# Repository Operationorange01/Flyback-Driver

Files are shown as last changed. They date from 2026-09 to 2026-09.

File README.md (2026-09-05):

This is a driver for a High Voltage Flyback Transformer. 
we are planning on using it in the next stage in our research on EHD propulsion. You can read our preprint from last year here: https://doi.org/10.31224/6625

Features:
 - Variable duty cycle
 - Variable frequency
 - Current/Voltage Sensing
 - Current/Voltage Regulating 6V to 25V, digitally adjustable via 12-bit DAC about 5mV resolution
 - Rotary encoder for control
 - OLED Display
 - Indicator Lights
 - Soft Startup
 - Hardware overcurrent protection, independent of firmware
 - Latching fault shutdown
 - Adjustable trip threshold
 - RCD clamp with tunable clamp voltage

No firmware yet but coming soon

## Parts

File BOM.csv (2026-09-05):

Country of Origin may be different at time of shipment.
The HTSUS and ECCN information shown is for informational purposes only and is not a representation or warranty as to the accuracy or reliability of these classifications. All information is provided "as is" and is subject to change without notice. Any use made of the information provided is without recourse to Digi-Key and at the user's risk.
Index | Manufacturer Part Number | Manufacturer Name | Description | Lead Time | Availability | Stock Status | Attrition % | Requested Quantity 1 | Pack Quantity 1 | Pack Type 1 | Digi-Key Part Number 1 | Unit Price 1 | Extended Price 1 | Minimum Order Quantity 1 | Customer Reference | Requested Part Number | Lead Weeks | Datasheet | Reference Designator | US Import Tariff | Note | Part Status | RoHS Status | REACH Status | Moisture Sensitivity Level (MSL) | ECCN | HTSUS | Country of Origin | Environmental Information | Original Part numbers | Unit of Measure | Image | Product Notes
1 | 78439369150 | Würth Elektronik | FIXED IND 15UH 8.3A 14.8 MOHM |  | 1,296 | In Stock |  | 1 | 1 | Cut Tape (CT) | 732-78439369150CT-ND | 5.27000 | $5.27 | 1 |  | 732-78439369150TR-ND | 43 | https://www.we-online.com/components/products/datasheet/78439369150.pdf |  | May apply on shipments to the U.S. |  | Active | ROHS3 Compliant | REACH Unaffected | 1 (Unlimited) | EAR99 | 8504.50.8000 | China | https://mm.digikey.com/Volume0/opasdata/d220001/medias/docus/744/Certificate_of_Compliance_ROHS.pdf | 732-78439369150TR-ND | Each | https://mm.digikey.com/Volume0/opasdata/d220001/medias/images/4170/MFG_WE-XHMA_7843xxxxxxx.jpg
2 | LCXND4040TKL2R2MDG | Taiyo Yuden | FIXED IND 2.2UH 2.2A 42 MOHM SMD |  | 2,876 | In Stock |  | 1 | 1 | Cut Tape (CT) | 587-LCXND4040TKL2R2MDGCT-ND | 0.30000 | $0.30 | 1 |  | 587-LCXND4040TKL2R2MDGTR-ND | 16 | https://mm.digikey.com/Volume0/opasdata/d220001/medias/docus/5883/LCXND4040TKL2R2MDG_SS.pdf |  | May apply on shipments to the U.S. |  | Active | ROHS3 Compliant | REACH Unaffected | 1 (Unlimited) | EAR99 | 8504.50.8000 | Philippines |  | 587-LCXND4040TKL2R2MDGTR-ND | Each | https://mm.digikey.com/Volume0/opasdata/d220001/medias/images/3541/MFG_LCXND4040TKL2R2MDG.jpg
3 | DR127-151-R | Eaton - Electronics Division | FIXED IND 150UH 1.59A 247 MOHM |  | 21,450 | In Stock |  | 1 | 1 | Cut Tape (CT) | 283-DR127-151-RCT-ND | 0.88000 | $0.88 | 1 |  | 283-DR127-151-RTR-ND | 24 | https://www.eaton.com/content/dam/eaton/products/electronic-components/resources/data-sheet/eaton-dr-high-power-density-high-efficiency-shielded-drum-core-pow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 |  | May apply on shipments to the U.S. |  | Active | ROHS3 Compliant | REACH Unaffected | 1 (Unlimited) | EAR99 | 8504.50.4000 | China |  | 283-DR127-151-RTR-ND | Each | https://mm.digikey.com/Volume0/opasdata/d220001/medias/images/567/DR127-151-R.JPG
4 | EC11E15244B2 | Alps Alpine | ENCODER MECH QUAD VERT PC PIN |  | 1,052 | In Stock |  | 1 | 1 | Tray | 4809-EC11E15244B2-ND | 5.00000 | $5.00 | 1 |  | 4809-EC11E15244B2-ND | 20 | https://mm.digikey.com/Volume0/opasdata/d220001/medias/docus/6727/alps_alps-s-a0008379064-1-1733314-1-13.pdf |  | May apply on shipments to the U.S. |  | Active | ROHS3 Compliant |  | 1 (Unlimited) | EAR99 | 8543.70.4500 | China |  | 4809-EC11E15244B2-ND | Each | https://mm.digikey.com/Volume0/opasdata/d220001/medias/images/5373/MFG_EC11E15244B2.jpg
5 | STM32F103C8T6 | STMicroelectronics | IC MCU 32BIT 64KB FLASH 48LQFP |  | 8,319 | In Stock |  | 1 | 1 | Tray | 497-6063-ND | 8.24000 | $8.24 | 1 |  | 497-6063-ND | 40 | https://www.st.com/resource/en/datasheet/stm32f103cb.pdf |  | May apply on shipments to the U.S. |  | Active | ROHS3 Compliant | REACH Unaffected | 3 (168 Hours) | 3A991A2 | 8542.31.0025 | Taiwan |  | 497-6063-ND | Each | https://mm.digikey.com/Volume0/opasdata/d220001/medias/images/389/48-LQFP.jpg
6 | UCC27511ADBVR | Texas Instruments | IC GATE DRVR LOW-SIDE SOT23-6 |  | 2,033 | In Stock |  | 1 | 1 | Cut Tape (CT) | 296-49474-1-ND | 1.14000 | $1.14 | 1 |  | 296-49474-2-ND | 16 | https://www.ti.com/general/docs/suppproductinfo.tsp?distId=10 |  | May apply on shipments to the U.S. |  | Active | ROHS3 Compliant | REACH Unaffected | 2 (1 Year) | EAR99 | 8542.39.0070 | China |  | 296-49474-2-ND | Each | https://mm.digikey.com/Volume0/opasdata/d220001/derivates/6/003/245/337/MFG_296%7E4073253-5%7EDBV%7E6_web%28640x640%29.jpg
7 | MCP4725A0T-E/CH | Microchip Technology | IC DAC 12BIT SOT-23-6 |  | 16,209 | In Stock |  | 2 | 2 | Cut Tape (CT) | MCP4725A0T-E/CHCT-ND | 1.27000 | $2.54 | 1 |  | MCP4725A0T-E/CHCT-ND | 13 | https://ww1.microchip.com/downloads/aemDocuments/documents/MSLD/ProductDocuments/DataSheets/MCP4725-Data-Sheet-20002039E.pdf |  | May apply on shipments to the U.S. |  | Active | ROHS3 Compliant | REACH Unaffected | 1 (Unlimited) | EAR99 | 8542.39.0040 | Thailand | https://ww1.microchip.com/downloads/aemDocuments/documents/corporate-responsibilty/environmental/product-regulatory-information/Semiconductor_EnvCoC.pdf|https://ww1.microchip.com/downloads/aemDocuments/documents/corporate-responsibilty/environmental/product-regulatory-information/Microchip_REACH_Statement.pdf | MCP4725A0T-E/CHCT-ND | Each | https://mm.digikey.com/Volume0/opasdata/d220001/derivates/6/003/238/121/MFG_150%7EC04-028%7ECH%2COT%7E6_web%28640x640%29.jpg
8 | INA226AIDGSR | Texas Instruments | IC CURRENT MONITOR 0.02% 10VSSOP |  | 94,948 | In Stock |  | 1 | 1 | Cut Tape (CT) | 296-29034-1-ND | 2.82000 | $2.82 | 1 |  | 296-29034-1-ND | 16 | https://www.ti.com/general/docs/suppproductinfo.tsp?distId=10 |  | May apply on shipments to the U.S. |  | Active | ROHS3 Compliant | REACH Unaffected | 2 (1 Year) | EAR99 | 8542.39.0070 | China |  | 296-29034-1-ND | Each | https://mm.digikey.com/Volume0/opasdata/d220001/medias/images/4190/296%7E4073272%7EDGS%7E10.JPG
9 | LM5117PSQ/NOPB | Texas Instruments | IC REG CTRLR BUCK 24WQFN |  | 4,037 | In Stock |  | 1 | 1 | Cut Tape (CT) | 296-LM5117PSQ/NOPBCT-ND | 7.46000 | $7.46 | 1 |  | 296-LM5117PSQ/NOPBCT-ND | 9 | https://www.ti.com/general/docs/suppproductinfo.tsp?distId=10 |  | - |  | Active | ROHS3 Compliant | REACH Unaffected | 1 (Unlimited) | EAR99 | 8542.39.0070 | Malaysia |  | 296-LM5117PSQ/NOPBCT-ND | Each | https://mm.digikey.com/Volume0/opasdata/d220001/medias/images/698/296%7E4206244%7ERTW%7E24.JPG
10 | LM2596S-ADJ | UMW | IC REG BUCK ADJ 3A TO263-5L |  | 98 | In Stock |  | 1 | 1 | Cut Tape (CT) | 4518-LM2596S-ADJCT-ND | 3.42000 | $3.42 | 1 |  | 4518-LM2596S-ADJCT-ND | 8 | https://www.umw-ic.com/static/pdf/08a395a0d66ae7472f74e2947a1d8a0f.pdf |  | - |  | Active | ROHS3 Compliant | REACH Unaffected | 1 (Unlimited) | EAR99 | 8542.39.0060 | China | https://mm.digikey.com/Volume0/opasdata/d220001/medias/docus/5791/UTD%20REACH%20SGS%20223%20Jan%202022%20Package.pdf|https://mm.digikey.com/Volume0/opasdata/d220001/medias/docus/5791/UTD%20RoHS3%20SGS%20Package.pdf | 4518-LM2596S-ADJCT-ND | Each | https://mm.digikey.com/Volume0/opasdata/d220001/medias/images/3602/MFG_LM2596S-ADJ%281%29.jpg
11 | TPS62130RGTT | Texas Instruments | IC REG BUCK ADJ 3A 16VQFN |  | 2,406 | In Stock |  | 1 | 1 | Cut Tape (CT) | 296-29934-1-ND | 3.07000 | $3.07 | 1 |  | 296-29934-2-ND | 16 | https://www.ti.com/general/docs/suppproductinfo.tsp?distId=10 |  | May apply on shipments to the U.S. |  | Active | ROHS3 Compliant | REACH Unaffected | 2 (1 Year) | EAR99 | 8542.39.0070 | China |  | 296-37682-1-ND | Each | https://mm.digikey.com/Volume0/opasdata/d220001/medias/images/4117/296%7E4222419%7ERGT%7E16.JPG
12 | LM393DR | Texas Instruments | IC COMPARATOR 2CH 8-SOIC |  | 131,872 | In Stock |  | 1 | 1 | Cut Tape (CT) | 296-1015-1-ND | 0.24000 | $0.24 | 1 |  | 296-1015-1-ND | 16 | https://www.ti.com/lit/ds/symlink/lm193.pdf?ts=1640569642482 |  | May apply on shipments to the U.S. |  | Active | ROHS3 Compliant | REACH Unaffected | 1 (Unlimited) | EAR99 | 8542.39.0090 | Mexico |  | 296-1015-1-ND | Each | https://mm.digikey.com/Volume0/opasdata/d220001/derivates/6/003/251/211/MFG_296%7E4040047-3%7ED%7E8_web%28640x640%29.jpg
13 | 74HC132D | Toshiba Semiconductor and Storage | IC NAND 4-CIR 2-IN 14-SOIC |  | 3,528 | In Stock - Non-Stock |  | 1 | 1 | Cut Tape (CT) | 264-74HC132DCT-ND | 0.43000 | $0.43 | 1 |  | 264-74HC132DCT-ND | 52 |  |  | - |  | Obsolete | ROHS3 Compliant | REACH Unaffected | 1 (Unlimited) | EAR99 | 8542.39.0070 | Japan |  | 264-74HC132DCT-ND | Each | https://mm.digikey.com/Volume0/opasdata/d220001/medias/images/2245/264%3B14SOIC-3.9%3B%3B14.jpg | Non Cancellable Non Returnable.
14 | IRFP460PBF | Vishay Siliconix | MOSFET N-CH 500V 20A TO247-3 |  | 18,673 | In Stock |  | 2 | 2 | Tube | IRFP460PBF-ND | 9.39000 | $18.78 | 1 |  | IRFP460PBF-ND | 27 | https://www.vishay.com/docs/91237/91237.pdf |  | May apply on shipments to the U.S. |  | Active | ROHS3 Compliant | REACH Unaffected | 1 (Unlimited) | EAR99 | 8541.29.0055 | United Kingdom |  | IRFP460PBF-ND | Each | https://mm.digikey.com/Volume0/opasdata/d220001/derivates/6/003/212/994/742%7E5971%7EP%7E3_web%28640x640%29.jpg
15 | IRF4905PBF | Infineon Technologies | MOSFET P-CH 55V 74A TO220AB |  | 39,590 | In Stock |  | 1 | 1 | Tube | IRF4905PBF-ND | 3.26000 | $3.26 | 1 |  | IRF4905PBF-ND | 16 | https://www.infineon.com/dgdl/irf4905pbf.pdf?fileId=5546d462533600a4015355e329b1197e |  | May apply on shipments to the U.S. |  | Active | ROHS3 Compliant | REACH Unaffected | 1 (Unlimited) | EAR99 | 8541.29.0055 | China |  | IRF4905PBF-ND | Each | https://mm.digikey.com/Volume0/opasdata/d220001/derivates/6/003/238/574/TO-220AB%2CTO-220-3%2CHEXFET%C2%AE_web%28640x640%29.jpg
16 | IRLZ44NPBF | Infineon Technologies | MOSFET N-CH 55V 47A TO220AB |  | 28,258 | In Stock |  | 2 | 2 | Tube | IRLZ44NPBF-ND | 1.80000 | $3.60 | 1 |  | IRLZ44NPBF-ND | 26 | https://www.infineon.com/dgdl/irlz44npbf.pdf?fileId=5546d462533600a40153567217c32725 |  | May apply on shipments to the U.S. |  | Active | ROHS3 Compliant | REACH Unaffected | 1 (Unlimited) | EAR99 | 8541.29.0055 | China |  | IRLZ44NPBF-ND | Each | https://mm.digikey.com/Volume0/opasdata/d220001/derivates/6/003/238/574/TO-220AB%2CTO-220-3%2CHEXFET%C2%AE_web%28640x640%29.jpg
17 | SMAJ12CA | Littelfuse Inc. | TVS DIODE 12VWM 19.9VC DO214AC |  | 28,364 | In Stock |  | 1 | 1 | Cut Tape (CT) | SMAJ12CALFCT-ND | 0.48000 | $0.48 | 1 |  | SMAJ12CALFCT-ND | 22 | https://www.littelfuse.com/assetdocs/tvs-diodes-smaj-datasheet?assetguid=13c2a823-03b8-4d1f-9ddc-9b44670aed9d |  | May apply on shipments to the U.S. |  | Active | ROHS3 Compliant | REACH Affected | 1 (Unlimited) | EAR99 | 8541.10.0080 | China | https://www.littelfusebusinesscenter.com/LFWeb/rohs_upload/RoHS_Certificate_of_Compliance/CoC_RoHS9_SMAJ12CA_05-08-2018.pdf | SMAJ12CALFCT-ND | Each | https://mm.digikey.com/Volume0/opasdata/d220001/derivates/6/001/123/964/118%7EDO214AC%28SMA%29%7E%7E2_web%28640x640%29.jpg
18 | SMCJ33A | Littelfuse Inc. | TVS DIODE 33VWM 53.3VC DO214AB |  | 60,353 | In Stock |  | 1 | 1 | Cut Tape (CT) | SMCJ33ALFCT-ND | 0.94000 | $0.94 | 1 |  | SMCJ33ALFCT-ND | 34 | https://www.littelfuse.com/assetdocs/littelfuse_tvs_diode_smcj_datasheet.pdf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 |  | May apply on shipments to the U.S. |  | Active | ROHS3 Compliant | REACH Affected | 1 (Unlimited) | EAR99 | 8541.10.0080 | China | https://www.littelfusebusinesscenter.com/LFWeb/rohs_upload/RoHS_Certificate_of_Compliance/CoC_RoHS9_SMCJ33A_06-13-2018.pdf | SMCJ33ALFCT-ND | Each | https://mm.digikey.com/Volume0/opasdata/d220001/derivates/6/003/248/763/MFG_18%7EDO214AB%28SMCJ%29%7E%7E2_web%28640x640%29.jpg
19 | 1N4148 | onsemi | DIODE STANDARD 100V 200MA DO35 |  | 727,505 | In Stock |  | 1 | 1 | Bulk | 1N4148FS-ND | 0.10000 | $0.10 | 1 |  | 1N4148FS-ND | 62 | https://www.onsemi.com/pub/Collateral/1N914-D.PDF |  | May apply on shipments to the U.S. |  | Active | ROHS3 Compliant | REACH Unaffected | Not Applicable | EAR99 | 8541.10.0070 | China | https://www.onsemi.com/site/pdf/RoHS-statement.pdf|https://www.onsemi.com/PowerSolutions/MaterialComposition.do?export=pdf&opnId=1N4148 | 1N4148FS-ND | Each | https://mm.digikey.com/Volume0/opasdata/d220001/medias/images/649/1N5229BFS.jpg
20 | SS36 | Taiwan Semiconductor Corporation | DIODE SCHOTTKY 60V 3A DO214AB |  | 8,916 | In Stock |  | 1 | 1 | Cut Tape (CT) | 1801-SS36CT-ND | 0.79000 | $0.79 | 1 |  | 1801-SS36CT-ND | 13 | https://services.taiwansemi.com/storage/resources/datasheet/SS32%20SERIES_Q2412.pdf |  | May apply on shipments to the U.S. |  | Active | ROHS3 Compliant | REACH Affected | 1 (Unlimited) | EAR99 | 8541.10.0080 | Taiwan | https://www.taiwansemi.com/en/wp-content/uploads/2023/12/Environment_Hazardous_Substances_Compliance_20231115.pdf|https://www.taiwansemi.com/en/wp-content/uploads/2023/12/REACH_regulation1907_2006_EC_compliance_240%20SVHCs_20240124_Web.pdf|https://services.taiwansemi.com/storage/resources/environmental_information/REACH%20regulation%20compliance_ANNEX%20XVII_20250708_Web.pdf|https://www.taiwansemi.com/en/wp-content/uploads/2023/12/California%20Proposition%2065%20Compliance_20240124_Web.pdf | 1801-SS36CT-ND | Each | https://mm.digikey.com/Volume0/opasdata/d220001/medias/images/6167/1801%7EDO214AB%28SMC%29%7E%7E2.jpg
21 | UF4007 | Taiwan Semiconductor Corporation | DIODE STANDARD 1000V 1A DO204AL |  | 1,259 | In Stock |  | 1 | 1 | Cut Tape (CT) | 1801-UF4007CT-ND | 0.42000 | $0.42 | 1 |  | 1801-UF4007CT-ND | 8 | https://services.taiwansemi.com/storage/resources/datasheet/UF4001%20SERIES_P2104.pdf |  | May apply on shipments to the U.S. |  | Active | ROHS3 Compliant | REACH Affected | 1 (Unlimited) | EAR99 | 8541.10.0080 | China | https://www.taiwansemi.com/en/wp-content/uploads/2023/12/Environment_Hazardous_Substances_Compliance_20231115.pdf|https://www.taiwansemi.com/en/wp-content/uploads/2023/12/REACH_regulation1907_2006_EC_compliance_240%20SVHCs_20240124_Web.pdf|https://services.taiwansemi.com/storage/resources/environmental_information/REACH%20regulation%20compliance_ANNEX%20XVII_20250708_Web.pdf|https://www.taiwansemi.com/en/wp-content/uploads/2023/12/California%20Proposition%2065%20Compliance_20240124_Web.pdf | 1801-UF4007CT-ND | Each | https://mm.digikey.com/Volume0/opasdata/d220001/medias/images/6285/1801%7EDO41%7E%7E2.jpg
22 | 1N4742A | onsemi | DIODE ZENER 12V 1W DO41 |  | 29,376 | In Stock |  | 1 | 1 | Bulk | 1N4742AFS-ND | 0.28000 | $0.28 | 1 |  | 1N4742AFS-ND | 50 | https://www.onsemi.com/pdf/datasheet/1n4736at-d.pdf |  | May apply on shipments to the U.S. |  | Active | ROHS3 Compliant | REACH Unaffected | Not Applicable | EAR99 | 8541.10.0050 | China | https://www.onsemi.com/site/pdf/RoHS-statement.pdf|https://www.onsemi.com/PowerSolutions/MaterialComposition.do?export=pdf&opnId=1N4742A | 1N4742AFS-ND | Each | https://mm.digikey.com/Volume0/opasdata/d220001/medias/images/6164/488%7EMKT-DO41A%7E%7E2.jpg
23 | CRF2512-FZ-R033ELF | Bourns Inc. | RES 0.033 OHM 1% 1W 2512 |  | 1,900 | In Stock |  | 1 | 1 | Cut Tape (CT) | CRF2512-FZ-R033ELFCT-ND | 0.49000 | $0.49 | 1 |  | CRF2512-FZ-R033ELFCT-ND | 23 | https://www.bourns.com/docs/Product-Datasheets/CRF.pdf |  | May apply on shipments to the U.S. |  | Active | ROHS3 Compliant | REACH Unaffected | 1 (Unlimited) | EAR99 | 8533.21.0030 | Taiwan | https://www.bourns.com/docs/Product-MDS/CRF2512_mds.pdf|https://mm.digikey.com/Volume0/opasdata/d220001/medias/docus/6657/Bourns%20REACH%20247%20Jan%202025%20Statement.pdf|https://www.bourns.com/docs/rohs-cofc/crx_coc2.pdf?sfvrsn=da0774f6_12 | CRF2512-FZ-R033ELFCT-ND | Each | https://mm.digikey.com/Volume0/opasdata/d220001/medias/images/4280/cmp2010.jpg
24 | WSL2512R0150FEA | Vishay Dale | RES 0.015 OHM 1% 1W 2512 |  | 12,011 | In Stock |  | 1 | 1 | Cut Tape (CT) | WSLG-.015CT-ND | 1.34000 | $1.34 | 1 |  | WSLG-.015CT-ND | 38 | https://www.vishay.com/docs/30100/wsl.pdf |  | May apply on shipments to the U.S. |  | Active | ROHS3 Compliant | REACH Unaffected | 1 (Unlimited) | EAR99 | 8533.21.0030 | Mexico |  | WSLG-.015CT-ND | Each | https://mm.digikey.com/Volume0/opasdata/d220001/derivates/6/002/690/354/WSL%202512_web%28640x640%29.jpg
25 | RSMF2JT100K | Stackpole Electronics Inc | RES 100K OHM 5% 2W AXIAL |  | 23,671 | In Stock |  | 1 | 1 | Cut Tape (CT) | RSMF2JT100KCT-ND | 0.19000 | $0.19 | 1 |  | RSMF2JT100KCT-ND | 19 | https://www.seielect.com/catalog/SEI-RSF_RSMF.pdf |  | May apply on shipments to the U.S. |  | Active | ROHS3 Compliant | REACH Unaffected | Not Applicable | EAR99 | 8533.21.0090 | China | https://www.seielect.com/catalog/SEI-RoHS_Compliance_Status.pdf|https://www.seielect.com/catalog/reach.pdf|https://www.seielect.com/catalog/sei-coc%20prop%2065.pdf | RSMF2JT100KCT-ND | Each | https://mm.digikey.com/Volume0/opasdata/d220001/medias/images/2498/100k-Ohm-RS%28M%29F-5%25-Axial-bl.jpg
26 | RK73H2ATTD1002F | KOA Speer Electronics, Inc. | RES 10K OHM 1% 1/4W 0805 |  | 1,155,716 | In Stock |  | 15 | 15 | Cut Tape (CT) | 2019-RK73H2ATTD1002FCT-ND | 0.03400 | $0.51 | 1 |  | 2019-RK73H2ATTD1002FCT-ND | 7 | https://www.koaspeer.com/pdfs/RK73H.pdf |  | May apply on shipments to the U.S. |  | Active | ROHS3 Compliant | REACH Unaffected | 1 (Unlimited) | EAR99 | 8533.21.0030 | Malaysia | https://www.koaglobal.com/product/common/rohs|https://mm.digikey.com/Volume0/opasdata/d220001/medias/docus/5718/2019_KOA%20Speer%20RoHS3%20Statement.pdf|https://mm.digikey.com/Volume0/opasdata/d220001/medias/docus/8955/KOA%20Speer%20CA%20Prop%2065%20Statement.pdf | 2019-RK73H2ATTD1002FCT-ND | Each | https://mm.digikey.com/Volume0/opasdata/d220001/medias/images/5572/MFG_RK73H1HTTCM12R7D.jpg
27 | RK73H2ATTD10R0F | KOA Speer Electronics, Inc. | RES 10 OHM 1% 1/4W 0805 |  | 210,232 | In Stock |  | 5 | 5 | Cut Tape (CT) | 2019-RK73H2ATTD10R0FCT-ND | 0.10000 | $0.50 | 1 |  | 2019-RK73H2ATTD10R0FCT-ND | 7 | https://www.koaspeer.com/pdfs/RK73H.pdf |  | May apply on shipments to the U.S. |  | Active | ROHS3 Compliant | REACH Unaffected | 1 (Unlimited) | EAR99 | 8533.21.0030 | Malaysia | https://www.koaglobal.com/product/common/rohs|https://mm.digikey.com/Volume0/opasdata/d220001/medias/docus/5718/2019_KOA%20Speer%20RoHS3%20Statement.pdf|https://mm.digikey.com/Volume0/opasdata/d220001/medias/docus/8955/KOA%20Speer%20CA%20Prop%2065%20Statement.pdf | 2019-RK73H2ATTD10R0FCT-ND | Each | https://mm.digikey.com/Volume0/opasdata/d220001/medias/images/5572/MFG_RK73H1HTTCM12R7D.jpg
28 | RK73H2ATTD3300F | KOA Speer Electronics, Inc. | RES 330 OHM 1% 1/4W 0805 |  | 80,638 | In Stock |  | 5 | 5 | Cut Tape (CT) | 2019-RK73H2ATTD3300FCT-ND | 0.10000 | $0.50 | 1 |  | 2019-RK73H2ATTD3300FCT-ND | 7 | https://www.koaspeer.com/pdfs/RK73H.pdf |  | May apply on shipments to the U.S. |  | Active | ROHS3 Compliant | REACH Unaffected | 1 (Unlimited) | EAR99 | 8533.21.0030 | Malaysia | https://www.koaglobal.com/product/common/rohs|https://mm.digikey.com/Volume0/opasdata/d220001/medias/docus/5718/2019_KOA%20Speer%20RoHS3%20Statement.pdf|https://mm.digikey.com/Volume0/opasdata/d220001/medias/docus/8955/KOA%20Speer%20CA%20Prop%2065%20Statement.pdf | 2019-RK73H2ATTD3300FCT-ND | Each | https://mm.digikey.com/Volume0/opasdata/d220001/medias/images/5572/MFG_RK73H1HTTCM12R7D.jpg
29 | RK73H2ATTD1003F | KOA Speer Electronics, Inc. | RES 100K OHM 1% 1/4W 0805 |  | 520,148 | In Stock |  | 5 | 5 | Cut Tape (CT) | 2019-RK73H2ATTD1003FCT-ND | 0.10000 | $0.50 | 1 |  | 2019-RK73H2ATTD1003FCT-ND | 7 | https://www.koaspeer.com/pdfs/RK73H.pdf |  | May apply on shipments to the U.S. |  | Active | ROHS3 Compliant | REACH Unaffected | 1 (Unlimited) | EAR99 | 8533.21.0030 | Malaysia | https://www.koaglobal.com/product/common/rohs|https://mm.digikey.com/Volume0/opasdata/d220001/medias/docus/5718/2019_KOA%20Speer%20RoHS3%20Statement.pdf|https://mm.digikey.com/Volume0/opasdata/d220001/medias/docus/8955/KOA%20Speer%20CA%20Prop%2065%20Statement.pdf | 2019-RK73H2ATTD1003FCT-ND | Each | https://mm.digikey.com/Volume0/opasdata/d220001/medias/images/5572/MFG_RK73H1HTTCM12R7D.jpg
30 | RK73H2ATTD1001F | KOA Speer Electronics, Inc. | RES 1K OHM 1% 1/4W 0805 |  | 422,806 | In Stock |  | 3 | 3 | Cut Tape (CT) | 2019-RK73H2ATTD1001FCT-ND | 0.10000 | $0.30 | 1 |  | 2019-RK73H2ATTD1001FCT-ND | 7 | https://www.koaspeer.com/pdfs/RK73H.pdf |  | May apply on shipments to the U.S. |  | Active | ROHS3 Compliant | REACH Unaffected | 1 (Unlimited) | EAR99 | 8533.21.0030 | Malaysia | https://www.koaglobal.com/product/common/rohs|https://mm.digikey.com/Volume0/opasdata/d220001/medias/docus/5718/2019_KOA%20Speer%20RoHS3%20Statement.pdf|https://mm.digikey.com/Volume0/opasdata/d220001/medias/docus/8955/KOA%20Speer%20CA%20Prop%2065%20Statement.pdf | 2019-RK73H2ATTD1001FCT-ND | Each | https://mm.digikey.com/Volume0/opasdata/d220001/medias/images/5572/MFG_RK73H1HTTCM12R7D.jpg
31 | RK73H2ATTDD4701F | KOA Speer Electronics, Inc. | RES 4.7K OHM 1% 1/4W 0805 |  | 25,015 | In Stock |  | 3 | 3 | Cut Tape (CT) | 2019-RK73H2ATTDD4701FCT-ND | 0.10000 | $0.30 | 1 |  | 2019-RK73H2ATTDD4701FCT-ND | 7 | https://www.koaspeer.com/pdfs/RK73H.pdf |  | May apply on shipments to the U.S. |  | Active | ROHS3 Compliant | REACH Unaffected | 1 (Unlimited) | EAR99 | 8533.21.0030 | Malaysia | https://www.koaglobal.com/product/common/rohs|https://mm.digikey.com/Volume0/opasdata/d220001/medias/docus/5718/2019_KOA%20Speer%20RoHS3%20Statement.pdf|https://mm.digikey.com/Volume0/opasdata/d220001/medias/docus/8955/KOA%20Speer%20CA%20Prop%2065%20Statement.pdf | 2019-RK73H2ATTDD4701FCT-ND | Each | https://mm.digikey.com/Volume0/opasdata/d220001/medias/images/5572/MFG_RK73H1HTTCM12R7D.jpg
32 | RK73H2ATTD2201F | KOA Speer Electronics, Inc. | RES 2.2K OHM 1% 1/4W 0805 |  | 116,635 | In Stock |  | 3 | 3 | Cut Tape (CT) | 2019-RK73H2ATTD2201FCT-ND | 0.10000 | $0.30 | 1 |  | 2019-RK73H2ATTD2201FCT-ND | 7 | https://www.koaspeer.com/pdfs/RK73H.pdf |  | May apply on shipments to the U.S. |  | Active | ROHS3 Compliant | REACH Unaffected | 1 (Unlimited) | EAR99 | 8533.21.0030 | Malaysia | https://www.koaglobal.com/product/common/rohs|https://mm.digikey.com/Volume0/opasdata/d220001/medias/docus/5718/2019_KOA%20Speer%20RoHS3%20Statement.pdf|https://mm.digikey.com/Volume0/opasdata/d220001/medias/docus/8955/KOA%20Speer%20CA%20Prop%2065%20Statement.pdf | 2019-RK73H2ATTD2201FCT-ND | Each | https://mm.digikey.com/Volume0/opasdata/d220001/medias/images/5572/MFG_RK73H1HTTCM12R7D.jpg
33 | RK73H2ATTD4R70F | KOA Speer Electronics, Inc. | RES 4.7 OHM 1% 1/4W 0805 |  | 72,302 | In Stock |  | 2 | 2 | Cut Tape (CT) | 2019-RK73H2ATTD4R70FCT-ND | 0.10000 | $0.20 | 1 |  | 2019-RK73H2ATTD4R70FCT-ND | 7 | https://www.koaspeer.com/pdfs/RK73H.pdf |  | May apply on shipments to the U.S. |  | Active | ROHS3 Compliant | REACH Unaffected | 1 (Unlimited) | EAR99 | 8533.21.0030 | Malaysia | https://www.koaglobal.com/product/common/rohs|https://mm.digikey.com/Volume0/opasdata/d220001/medias/docus/5718/2019_KOA%20Speer%20RoHS3%20Statement.pdf|https://mm.digikey.com/Volume0/opasdata/d220001/medias/docus/8955/KOA%20Speer%20CA%20Prop%2065%20Statement.pdf | 2019-RK73H2ATTD4R70FCT-ND | Each | https://mm.digikey.com/Volume0/opasdata/d220001/medias/images/5572/MFG_RK73H1HTTCM12R7D.jpg
34 | RC0805FR-07100RL | YAGEO | RES 100 OHM 1% 1/8W 0805 |  | 900,404 | In Stock |  | 4 | 4 | Cut Tape (CT) | 311-100CRCT-ND | 0.10000 | $0.40 | 1 |  | 311-100CRCT-ND | 17 | https://yageogroup.com/content/datasheet/asset/file/PYU-RC_GROUP_51_ROHS_L |  | May apply on shipments to the U.S. |  | Active | ROHS3 Compliant | REACH Unaffected | 1 (Unlimited) | EAR99 | 8533.21.0030 | Taiwan | https://www.yageogroup.com/content/Resource%20Library/Product%20Environmental%20Compliance/RoHS_Compliance_YAGEO.pdf | 311-100CRCT-ND | Each | https://mm.digikey.com/Volume0/opasdata/d220001/derivates/6/003/121/213/cut-tape-render_web%28640x640%29.jpg
35 | CRCW08054K12FKEA | Vishay Dale | RES SMD 4.12K OHM 1% 1/8W 0805 |  | 17,569 | In Stock |  | 2 | 2 | Cut Tape (CT) | 541-4.12KCCT-ND | 0.10000 | $0.20 | 1 |  | 541-4.12KCCT-ND | 21 | https://www.vishay.com/docs/20035/dcrcwe3.pdf |  | May apply on shipments to the U.S. |  | Active | ROHS3 Compliant | REACH Unaffected | 1 (Unlimited) | EAR99 | 8533.21.0030 | Israel |  | 541-4.12KCCT-ND | Each | https://mm.digikey.com/Volume0/opasdata/d220001/medias/images/4849/541_CRCW-0805-%282125metric%29.jpg
36 | RC0805FR-077K32L | YAGEO | RES 7.32K OHM 1% 1/8W 0805 |  | 28,715 | In Stock |  | 2 | 2 | Cut Tape (CT) | 311-7.32KCRCT-ND | 0.10000 | $0.20 | 1 |  | 311-7.32KCRCT-ND | 17 | https://yageogroup.com/content/datasheet/asset/file/PYU-RC_GROUP_51_ROHS_L |  | May apply on shipments to the U.S. |  | Active | ROHS3 Compliant | REACH Unaffected | 1 (Unlimited) | EAR99 | 8533.21.0030 | Taiwan | https://www.yageogroup.com/content/Resource%20Library/Product%20Environmental%20Compliance/RoHS_Compliance_YAGEO.pdf | 311-7.32KCRCT-ND | Each | https://mm.digikey.com/Volume0/opasdata/d220001/medias/images/4848/13_0805-%282012-metric%29.jpg
37 | CRG0805F13K | TE Connectivity Passive Product | RES SMD 13K OHM 1% 1/8W 0805 |  | 247,688 | In Stock |  | 2 | 2 | Cut Tape (CT) | A126339CT-ND | 0.10000 | $0.20 | 1 |  | A126339CT-ND | 14 | https://www.te.com/commerce/DocumentDelivery/DDEController?Action=srchrtrv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 |  | - |  | Active | ROHS3 Compliant | Vendor Undefined | 1 (Unlimited) | EAR99 | 8533.21.0030 | Thailand | https://www.te.com/commerce/alt/SinglePartSearch.do?PN=1623112-1&dest=stmt | A126339CT-ND | Each | https://mm.digikey.com/Volume0/opasdata/d220001/medias/images/2453/CRG%2C%20Neohm%200805%20%282012%20Metric%29.jpg
38 | RMCF0805FT17K4 | Stackpole Electronics Inc | RES 17.4K OHM 1% 1/8W 0805 |  | 274,182 | In Stock |  | 2 | 2 | Cut Tape (CT) | RMCF0805FT17K4CT-ND | 0.11000 | $0.22 | 1 |  | RMCF0805FT17K4CT-ND | 22 | https://www.seielect.com/catalog/SEI-RMCF_RMCP.pdf |  | May apply on shipments to the U.S. |  | Active | ROHS3 Compliant | REACH Unaffected | 1 (Unlimited) | EAR99 | 8533.21.0030 | China | https://www.seielect.com/catalog/SEI-RoHS_Compliance_Status.pdf|https://www.seielect.com/catalog/reach.pdf|https://www.seielect.com/catalog/sei-coc%20prop%2065.pdf | RMCF0805FT17K4CT-ND | Each | https://mm.digikey.com/Volume0/opasdata/d220001/derivates/6/002/683/989/MFG_RMC%20SERIES_web%28640x640%29.jpg
39 | RMCF0805FT33K0 | Stackpole Electronics Inc | RES 33K OHM 1% 1/8W 0805 |  | 172,439 | In Stock |  | 2 | 2 | Cut Tape (CT) | RMCF0805FT33K0CT-ND | 0.10000 | $0.20 | 1 |  | RMCF0805FT33K0CT-ND | 22 | https://www.seielect.com/catalog/SEI-RMCF_RMCP.pdf |  | May apply on shipments to the U.S. |  | Active | ROHS3 Compliant | REACH Unaffected | 1 (Unlimited) | EAR99 | 8533.21.0030 | Taiwan | https://www.seielect.com/catalog/SEI-RoHS_Compliance_Status.pdf|https://www.seielect.com/catalog/reach.pdf|https://www.seielect.com/catalog/sei-coc%20prop%2065.pdf | RMCF0805FT33K0CT-ND | Each | https://mm.digikey.com/Volume0/opasdata/d220001/medias/images/639/0805-RMCF-Series.jpg
40 | RC0805FR-07130KL | YAGEO | RES 130K OHM 1% 1/8W 0805 |  | 49,537 | In Stock |  | 2 | 2 | Cut Tape (CT) | 311-130KCRCT-ND | 0.10000 | $0.20 | 1 |  | 311-130KCRCT-ND | 17 | https://yageogroup.com/content/datasheet/asset/file/PYU-RC_GROUP_51_ROHS_L |  | May apply on shipments to the U.S. |  | Active | ROHS3 Compliant | REACH Unaffected | 1 (Unlimited) | EAR99 | 8533.21.0030 | Taiwan | https://www.yageogroup.com/content/Resource%20Library/Product%20Environmental%20Compliance/RoHS_Compliance_YAGEO.pdf | 311-130KCRCT-ND | Each | https://mm.digikey.com/Volume0/opasdata/d220001/medias/images/4848/13_0805-%282012-metric%29.jpg
41 | RK73H2ATTD3003F | KOA Speer Electronics, Inc. | RES 300K OHM 1% 1/4W 0805 |  | 17,760 | In Stock |  | 2 | 2 | Cut Tape (CT) | 2019-RK73H2ATTD3003FCT-ND | 0.10000 | $0.20 | 1 |  | 2019-RK73H2ATTD3003FCT-ND | 7 | https://www.koaspeer.com/pdfs/RK73H.pdf |  | May apply on shipments to the U.S. |  | Active | ROHS3 Compliant | REACH Unaffected | 1 (Unlimited) | EAR99 | 8533.21.0030 | Malaysia | https://www.koaglobal.com/product/common/rohs|https://mm.digikey.com/Volume0/opasdata/d220001/medias/docus/5718/2019_KOA%20Speer%20RoHS3%20Statement.pdf|https://mm.digikey.com/Volume0/opasdata/d220001/medias/docus/8955/KOA%20Speer%20CA%20Prop%2065%20Statement.pdf | 2019-RK73H2ATTD3003FCT-ND | Each | https://mm.digikey.com/Volume0/opasdata/d220001/medias/images/5572/MFG_RK73H1HTTCM12R7D.jpg
42 | C0805C104K5RACTU | KEMET | CAP CER 0.1UF 50V X7R 0805 |  | 5,531,511 | In Stock |  | 16 | 16 | Cut Tape (CT) | 399-C0805C104K5RACTUCT-ND | 0.09100 | $1.46 | 1 |  | 399-C0805C104K5RACTUCT-ND | 21 | https://yageogroup.com/content/datasheet/asset/file/KEM_C1002_X7R_SMD |  | May apply on shipments to the U.S. |  | Active | ROHS3 Compliant | REACH Unaffected | 1 (Unlimited) | EAR99 | 8532.24.0020 | China |  | 399-C0805C104K5RACTUCT-ND | Each | https://mm.digikey.com/Volume0/opasdata/d220001/derivates/6/003/121/213/cut-tape-render_web%28640x640%29.jpg
43 | GRM21BR61E106MA73L | Murata Electronics | CAP CER 10UF 25V X5R 0805 |  | 17,947 | In Stock |  | 6 | 6 | Cut Tape (CT) | 490-10748-1-ND | 0.17000 | $1.02 | 1 |  | 490-10748-1-ND | 17 | https://mm.digikey.com/Volume0/opasdata/d220001/medias/docus/8942/490_Chip_Multilayer_CAT2021_MLCC.pdf |  | May apply on shipments to the U.S. |  | Active | ROHS3 Compliant | REACH Unaffected | 1 (Unlimited) | EAR99 | 8532.24.0020 | Japan |  | 490-10748-1-ND | Each | https://mm.digikey.com/Volume0/opasdata/d220001/medias/images/5447/490-Ceramic-Capacitor-Tan-Field.jpg
44 | C0805C105K3RACTU | KEMET | CAP CER 1UF 25V X7R 0805 |  | 446,395 | In Stock |  | 5 | 5 | Cut Tape (CT) | 399-C0805C105K3RACTUCT-ND | 0.16000 | $0.80 | 1 |  | 399-C0805C105K3RACTUCT-ND | 21 | https://yageogroup.com/content/datasheet/asset/file/KEM_C1002_X7R_SMD |  | May apply on shipments to the U.S. |  | Active | ROHS3 Compliant | REACH Unaffected | 1 (Unlimited) | EAR99 | 8532.24.0020 | Taiwan |  | 399-C0805C105K3RACTUCT-ND | Each | https://mm.digikey.com/Volume0/opasdata/d220001/derivates/6/003/121/213/cut-tape-render_web%28640x640%29.jpg
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

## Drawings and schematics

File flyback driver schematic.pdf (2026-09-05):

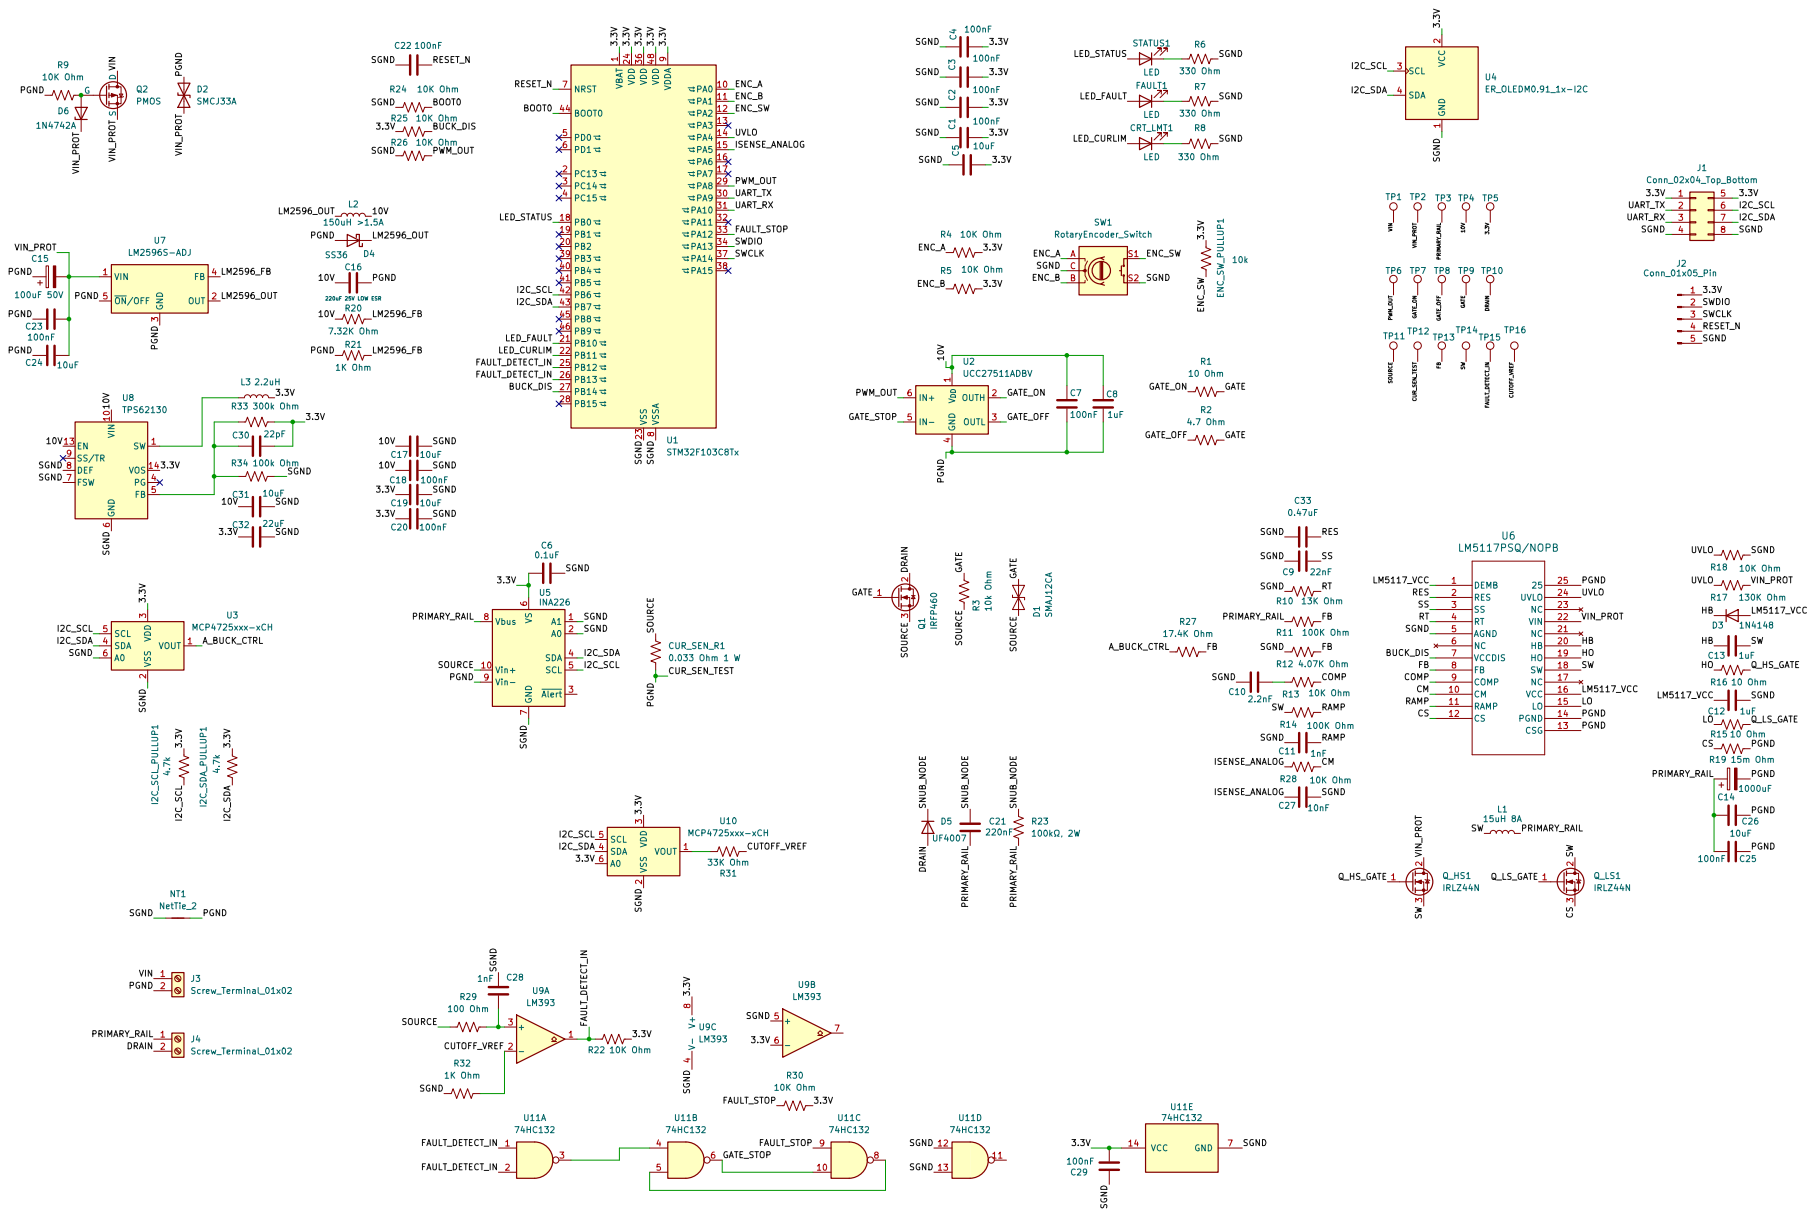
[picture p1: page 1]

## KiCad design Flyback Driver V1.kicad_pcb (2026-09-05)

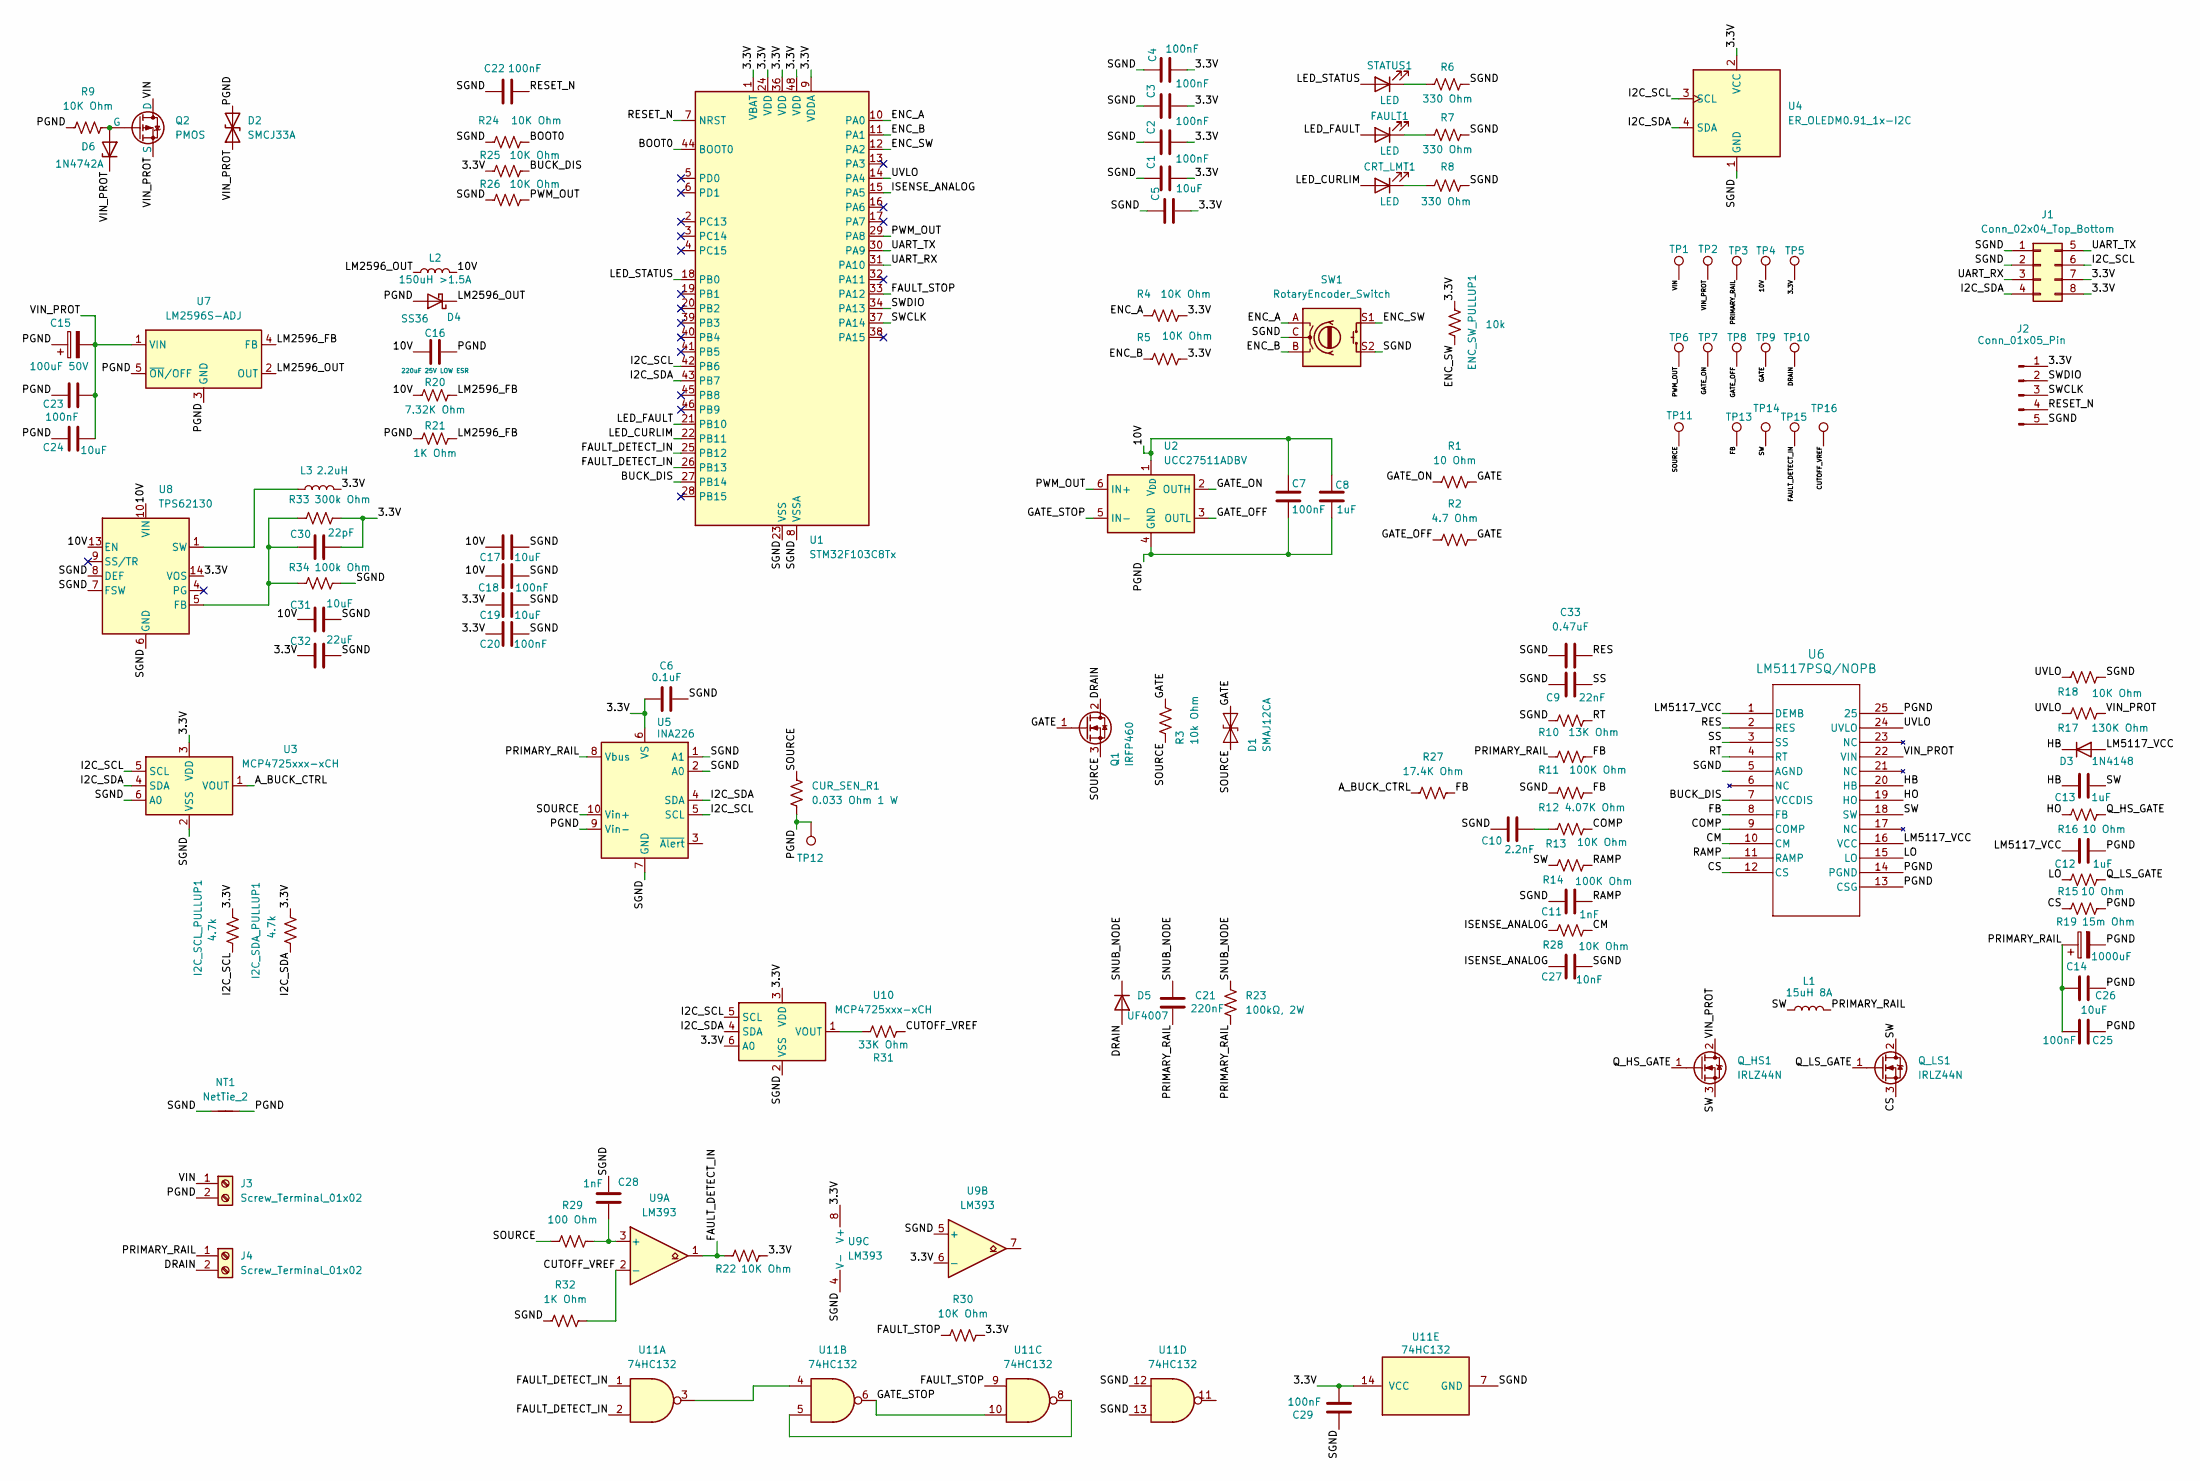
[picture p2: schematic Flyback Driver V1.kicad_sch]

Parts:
C1, C2, C3, C4, C7, C18, C20, C22, C23, C25, C29: 100nF; C_0805_2012Metric_Pad1.18x1.45mm_HandSolder
C5, C17, C19, C31: 10uF; C_0805_2012Metric_Pad1.18x1.45mm_HandSolder
C6: 0.1uF; C_0805_2012Metric_Pad1.18x1.45mm_HandSolder
C8, C12, C13: 1uF; C_0805_2012Metric_Pad1.18x1.45mm_HandSolder
C9: 22nF; C_0805_2012Metric_Pad1.18x1.45mm_HandSolder
C10: 2.2nF; C_0805_2012Metric_Pad1.18x1.45mm_HandSolder
C11, C28: 1nF; C_0805_2012Metric_Pad1.18x1.45mm_HandSolder
C14: 1000uF; CP_Radial_D12.5mm_P5.00mm
C15: 100uF 50V; CP_Radial_D8.0mm_P3.50mm
C16: 220uF 25V LOW ESR; CP_Radial_D8.0mm_P3.50mm
C21: 220nF; C_Rect_L18.0mm_W5.0mm_P15.00mm_FKS3_FKP3
C24, C26: 10uF; C_1210_3225Metric_Pad1.33x2.70mm_HandSolder
C27: 10nF; C_0805_2012Metric_Pad1.18x1.45mm_HandSolder
C30: 22pF; C_0805_2012Metric_Pad1.18x1.45mm_HandSolder
C32: 22uF; C_0805_2012Metric_Pad1.18x1.45mm_HandSolder
C33: 0.47uF; C_0805_2012Metric_Pad1.18x1.45mm_HandSolder
CRT_LMT1: LED; LED_0805_2012Metric_Pad1.15x1.40mm_HandSolder
CUR_SEN_R1: 0.033 Ohm 1 W; R_2512_6332Metric_Pad1.40x3.35mm_HandSolder
D1: SMAJ12CA; D_SMA
D2: SMCJ33A; D_SMC
D3: 1N4148; D_DO-35_SOD27_P7.62mm_Horizontal
D4: SS36; D_SMC
D5: UF4007; D_DO-41_SOD81_P10.16mm_Horizontal
D6: 1N4742A; D_DO-41_SOD81_P10.16mm_Horizontal
ENC_SW_PULLUP1: 10k; R_0805_2012Metric_Pad1.20x1.40mm_HandSolder
FAULT1: LED; LED_0805_2012Metric_Pad1.15x1.40mm_HandSolder
I2C_SCL_PULLUP1, I2C_SDA_PULLUP1: 4.7k; R_0805_2012Metric_Pad1.20x1.40mm_HandSolder
J1: Conn_02x04_Top_Bottom; PinHeader_2x04_P2.54mm_Vertical
J2: Conn_01x05_Pin; PinHeader_1x05_P2.54mm_Vertical
J3, J4: Screw_Terminal_01x02; TerminalBlock_Phoenix_MKDS-3-2-5.08_1x02_P5.08mm_Horizontal
L1: 15uH 8A; L_Wurth_WE-XHMA-1090
L2: 150uH >1.5A; INDM125125X800N
L3: 2.2uH; L_Taiyo-Yuden_LCXND4040
NT1: NetTie_2; NetTie-2_SMD_Pad0.5mm
Q1: IRFP460; TO-247-3_Vertical
Q2: PMOS; TO-220-3_Vertical
Q_HS1: IRLZ44N; TO-220-3_Vertical
Q_LS1: IRLZ44N; TO-220-3_Vertical
R1, R15, R16: 10 Ohm; R_0805_2012Metric_Pad1.20x1.40mm_HandSolder
R2: 4.7 Ohm; R_0805_2012Metric_Pad1.20x1.40mm_HandSolder
R3: 10k Ohm; R_0805_2012Metric_Pad1.20x1.40mm_HandSolder
R4, R5, R9, R13, R18, R22, R24, R25, R26, R28, R30: 10K Ohm; R_0805_2012Metric_Pad1.20x1.40mm_HandSolder
R6, R7, R8: 330 Ohm; R_0805_2012Metric_Pad1.20x1.40mm_HandSolder
R10: 13K Ohm; R_0805_2012Metric_Pad1.20x1.40mm_HandSolder
R11, R14: 100K Ohm; R_0805_2012Metric_Pad1.20x1.40mm_HandSolder
R12: 4.07K Ohm; R_0805_2012Metric_Pad1.20x1.40mm_HandSolder
R17: 130K Ohm; R_0805_2012Metric_Pad1.20x1.40mm_HandSolder
R19: 15m Ohm; R_2512_6332Metric_Pad1.40x3.35mm_HandSolder
R20: 7.32K Ohm; R_0805_2012Metric_Pad1.20x1.40mm_HandSolder
R21, R32: 1K Ohm; R_0805_2012Metric_Pad1.20x1.40mm_HandSolder
R23: 100kΩ, 2W; R_Axial_DIN0617_L17.0mm_D6.0mm_P25.40mm_Horizontal
R27: 17.4K Ohm; R_0805_2012Metric_Pad1.20x1.40mm_HandSolder
R29: 100 Ohm; R_0805_2012Metric_Pad1.20x1.40mm_HandSolder
R31: 33K Ohm; R_0805_2012Metric_Pad1.20x1.40mm_HandSolder
R33: 300k Ohm; R_0805_2012Metric_Pad1.20x1.40mm_HandSolder
R34: 100k Ohm; R_0805_2012Metric_Pad1.20x1.40mm_HandSolder
STATUS1: LED; LED_0805_2012Metric_Pad1.15x1.40mm_HandSolder
SW1: RotaryEncoder_Switch; RotaryEncoder_Alps_EC11E-Switch_Vertical_H20mm_MountingHoles
TP1, TP2, TP3, TP4, TP5, TP6, TP7, TP8, TP9, TP10, TP11, TP12, TP13, TP14, TP15, TP16: TestPoint; TestPoint_THTPad_D1.5mm_Drill0.7mm
U1: STM32F103C8Tx; LQFP-48_7x7mm_P0.5mm
U2: UCC27511ADBV; SOT-23-6
U3, U10: MCP4725xxx-xCH; SOT-23-6
U4: ER_OLEDM0.91_1x-I2C
U5: INA226; TSSOP-10_3x3mm_P0.5mm
U6: LM5117PSQ/NOPB; WQFN-24-1EP_4x4mm_P0.5mm_EP2.6x2.6mm_ThermalVias
U7: LM2596S-ADJ; TO-263-5_TabPin3
U8: TPS62130; VQFN-16-1EP_3x3mm_P0.5mm_EP1.68x1.68mm_ThermalVias
U9: LM393; SOIC-8_3.9x4.9mm_P1.27mm
U11: 74HC132; SOIC-14_3.9x8.7mm_P1.27mm

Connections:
/3.3V: C1.2, C2.2, C3.2, C4.2, C5.2, C6.1, C19.1, C20.1, C29.2, C30.2, C32.1, ENC_SW_PULLUP1.1, I2C_SCL_PULLUP1.1, I2C_SDA_PULLUP1.1, J1.7, J1.8, J2.1, L3.2, R4.1, R5.1, R22.2, R25.1, R30.2, R33.2, TP5.1 (1_1), U1.1 (VBAT), U1.9 (VDDA), U1.24 (VDD), U1.36 (VDD), U1.48 (VDD), U3.3 (VDD), U4.2 (VCC), U5.6 (VS), U8.14 (VOS), U9.6 (-), U9.8 (V+), U10.3 (VDD), U10.6 (A0), U11.14 (VCC)
/10V: C7.1, C8.1, C16.1, C17.1, C18.1, C31.1, L2.2, R20.1, TP4.1 (1_1), U2.1 (V_{DD}), U8.10 (VIN), U8.11 (VIN), U8.12 (VIN), U8.13 (EN)
/A_BUCK_CTRL: R27.1, U3.1 (VOUT)
/BOOT0: R24.2, U1.44 (BOOT0)
/BUCK_DIS: R25.2, U1.27 (PB14), U6.7 (VCCDIS)
/CM: R28.2, U6.10 (CM)
/COMP: R13.2, U6.9 (COMP)
/CS: Q_LS1.3 (S), R19.1, U6.12 (CS)
/CUTOFF_VREF: R31.2, R32.2, TP16.1 (1_1), U9.2 (-)
/DRAIN: D5.2 (A), J4.2, Q1.2 (D), TP10.1 (1_1)
/ENC_A: R4.2, SW1.A, U1.10 (PA0)
/ENC_B: R5.2, SW1.B, U1.11 (PA1)
/ENC_SW: ENC_SW_PULLUP1.2, SW1.S1, U1.12 (PA2)
/FAULT_DETECT_IN: R22.1, TP15.1 (1_1), U1.25 (PB12), U1.26 (PB13), U9.1, U11.1, U11.2
/FAULT_STOP: R30.1, U1.33 (PA12), U11.9
/FB: R11.2, R12.2, R27.2, TP13.1 (1_1), U6.8 (FB)
/GATE: D1.2 (A2), Q1.1 (G), R1.2, R2.2, R3.1, TP9.1 (1_1)
/GATE_OFF: R2.1, TP8.1 (1_1), U2.3 (OUTL)
/GATE_ON: R1.1, TP7.1 (1_1), U2.2 (OUTH)
/GATE_STOP: U2.5 (IN-), U11.6, U11.10
/HB: C13.1, D3.1 (K), U6.20 (HB)
/HO: R16.1, U6.19 (HO)
/I2C_SCL: I2C_SCL_PULLUP1.2, J1.6, U1.42 (PB6), U3.5 (SCL), U4.3 (SCL), U5.5 (SCL), U10.5 (SCL)
/I2C_SDA: I2C_SDA_PULLUP1.2, J1.4, U1.43 (PB7), U3.4 (SDA), U4.4 (SDA), U5.4 (SDA), U10.4 (SDA)
/ISENSE_ANALOG: C27.1, R28.1, U1.15 (PA5)
/LED_CURLIM: CRT_LMT1.2 (A), U1.22 (PB11); also elsewhere on the board
/LED_FAULT: FAULT1.2 (A), U1.21 (PB10); also elsewhere on the board
/LED_STATUS: STATUS1.2 (A), U1.18 (PB0); also elsewhere on the board
/LM2596_FB: R20.2, R21.2, U7.4 (FB)
/LM2596_OUT: D4.1 (K), L2.1, U7.2 (OUT)
/LM5117_VCC: C12.1, D3.2 (A), U6.1 (DEMB), U6.16 (VCC)
/LO: R15.1, U6.15 (LO)
/PGND: C7.2, C8.2, C12.2, C14.2, C15.1, C16.2, C23.1, C24.1, C25.1, C26.1, CUR_SEN_R1.2, D2.2 (A2), D4.2 (A), J3.2, NT1.2, R9.1, R19.2, R21.1, TP12.1 (1_1), U2.4 (GND), U5.9 (Vin-), U6.13 (CSG), U6.14 (PGND), U6.25, U7.3 (GND), U7.5 (~ON/OFF)
/PRIMARY_RAIL: C14.1, C21.2, C25.2, C26.2, J4.1, L1.2, R11.1, R23.2, TP3.1 (1_1), U5.8 (Vbus)
/PWM_OUT: R26.2, TP6.1 (1_1), U1.29 (PA8), U2.6 (IN+)
/Q_HS_GATE: Q_HS1.1 (G), R16.2
/Q_LS_GATE: Q_LS1.1 (G), R15.2
/RAMP: C11.2, R14.2, U6.11 (RAMP)
/RES: C33.2, U6.2 (RES)
/RESET_N: C22.2, J2.4, U1.7 (NRST)
/RT: R10.2, U6.4 (RT)
/SGND: C1.1, C2.1, C3.1, C4.1, C5.1, C6.2, C9.1, C10.2, C11.1, C17.2, C18.2, C19.2, C20.2, C22.1, C27.2, C28.1, C29.1, C31.2, C32.2, C33.1, J1.1, J1.2, J2.5, NT1.1, R6.2, R7.2, R8.2, R10.1, R12.1, R18.2, R24.1, R26.1, R32.1, R34.2, SW1.C, SW1.S2, U1.8 (VSSA), U1.23 (VSS), U1.35 (VSS), U1.47 (VSS), U3.2 (VSS), U3.6 (A0), U4.1 (GND), U5.1 (A1), U5.2 (A0), U5.7 (GND), U6.5 (AGND), U8.6 (GND), U8.7 (FSW), U8.8 (DEF), U8.15 (GND), U8.16 (GND), U8.17 (GND), U9.4 (V-), U9.5 (+), U10.2 (VSS), U11.7 (GND), U11.12, U11.13
/SNUB_NODE: C21.1, D5.1 (K), R23.1
/SOURCE: CUR_SEN_R1.1, D1.1 (A1), Q1.3 (S), R3.2, R29.1, TP11.1 (1_1), U5.10 (Vin+)
/SS: C9.2, U6.3 (SS)
/SW: C13.2, L1.1, Q_HS1.3 (S), Q_LS1.2 (D), R14.1, TP14.1 (1_1), U6.18 (SW)
/SWCLK: J2.3, U1.37 (PA14)
/SWDIO: J2.2, U1.34 (PA13)
/UART_RX: J1.3, U1.31 (PA10)
/UART_TX: J1.5, U1.30 (PA9)
/UVLO: R17.1, R18.1, U1.14 (PA4), U6.24 (UVLO)
/VIN: J3.1, Q2.1 (D), TP1.1 (1_1)
/VIN_PROT: C15.2, C23.2, C24.2, D2.1 (A1), D6.1 (K), Q2.3 (S), Q_HS1.2 (D), R17.2, TP2.1 (1_1), U6.22 (VIN), U7.1 (VIN)
unnamed: C10.1, R13.1
unnamed 54: CRT_LMT1.1 (K), R8.1; also elsewhere on the board
unnamed: D6.2 (A), Q2.2 (G), R9.2
unnamed 56: FAULT1.1 (K), R7.1; also elsewhere on the board
unnamed: L3.1, U8.1 (SW), U8.2 (SW), U8.3 (SW)
unnamed 58: R6.1, STATUS1.1 (K); also elsewhere on the board
unnamed: C30.1, R33.1, R34.1, U8.5 (FB)
unnamed: C28.2, R29.2, U9.3 (+)
unnamed: R31.1, U10.1 (VOUT)
unnamed: U11.3, U11.4
unnamed: U11.5, U11.8

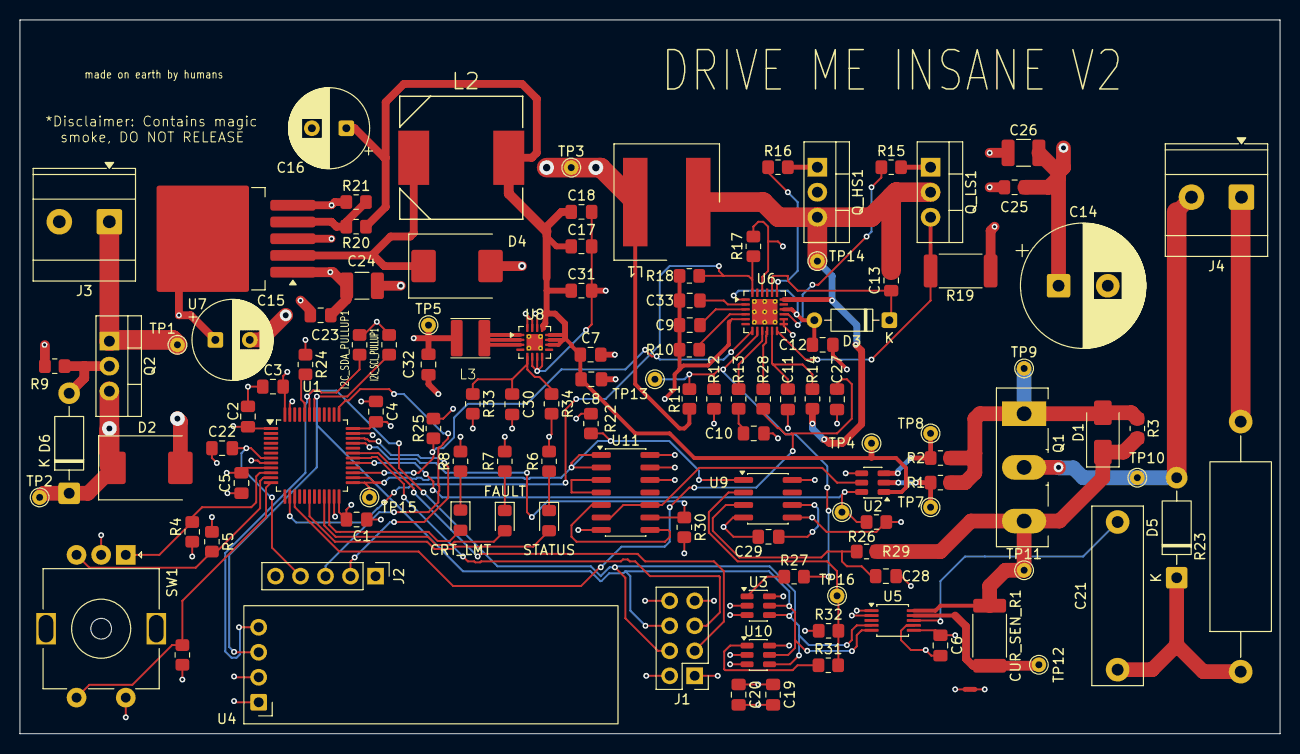
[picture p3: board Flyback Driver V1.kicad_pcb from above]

Board: 4 copper layers, 128.0 x 72.5 mm, 120 parts (0 on the bottom side), 64 nets.

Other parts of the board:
CRT_LMT: LED; LED_0805_2012Metric_Pad1.15x1.40mm_HandSolder
FAULT: LED; LED_0805_2012Metric_Pad1.15x1.40mm_HandSolder
STATUS: LED; LED_0805_2012Metric_Pad1.15x1.40mm_HandSolder

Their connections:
/LED_CURLIM: CRT_LMT.2 (A); also elsewhere on the board
/LED_FAULT: FAULT.2 (A); also elsewhere on the board
/LED_STATUS: STATUS.2 (A); also elsewhere on the board
unnamed 54: CRT_LMT.1 (K); also elsewhere on the board
unnamed 56: FAULT.1 (K); also elsewhere on the board
unnamed 58: STATUS.1 (K); also elsewhere on the board

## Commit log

2026-09-05 Added all files for pcb
    [Flyback Driver V1.kicad_pcb, Flyback Driver V1.kicad_sch]
2026-09-05 Added parts list for everything on digikey
    [Flyback Driver.csv]
2026-09-05 Rename Flyback Driver.csv to BOM.csv
    [BOM.csv]
